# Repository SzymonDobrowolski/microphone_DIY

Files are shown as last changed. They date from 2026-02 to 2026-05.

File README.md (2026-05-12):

# High-Fidelity DIY USB Microphone 🎙️






<br>

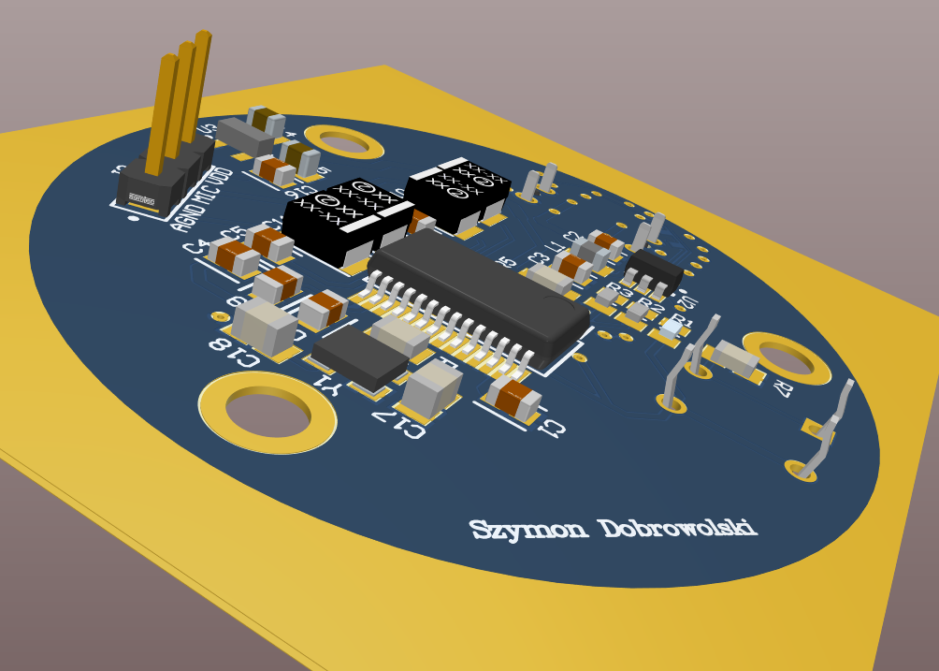
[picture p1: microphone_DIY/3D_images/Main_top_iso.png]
Main Board Isometric View


Welcome to the **High-Fidelity DIY USB Microphone** project repository! This project features a custom-designed, two-board USB audio interface and microphone preamplifier built from scratch. The primary goal of this project was to achieve a studio-grade vocal capture by combining a highly sensitive, interference-free custom PCB design with precise digital signal processing (DSP).

## 🌟 Key Features
* **Clean Signal Path:** Strict analog/digital isolation ensures the audio path is free from high-frequency digital bleed, coil whine, and USB packet noise.
* **Dual-Board Design:** Separates the noisy USB/Digital section (Main Board) from the highly sensitive analog preamplifier (Amp Board).
* **Advanced Power Filtering:** Features a $\pi$ (Pi) filter on the USB VBUS and a dedicated 3.3V LDO (MCP1700) with optimized decoupling.
* **Premium Analog Front-End:** Utilizes the ultra-low noise **OPA1688** operational amplifier to unleash the full dynamic range of high-end electret capsules like the **Primo AOM-5024L**.
* **Custom Acoustic Housing:** 3D-printed enclosure optimized for shock mounting and pop-filter integration to eliminate mechanical noise and plosives.
* **DSP Tuned:** Because the custom hardware captures the acoustic reality of the room with extreme sensitivity, precise real-time tuning (via SteelSeries Sonar) is applied to achieve a flawless broadcast character.

---

## ⚙️ Hardware Architecture

### 1. Main Board (USB Codec)
The main board handles USB communication, digital-to-analog/analog-to-digital conversion, and power regulation.

<p align="center">
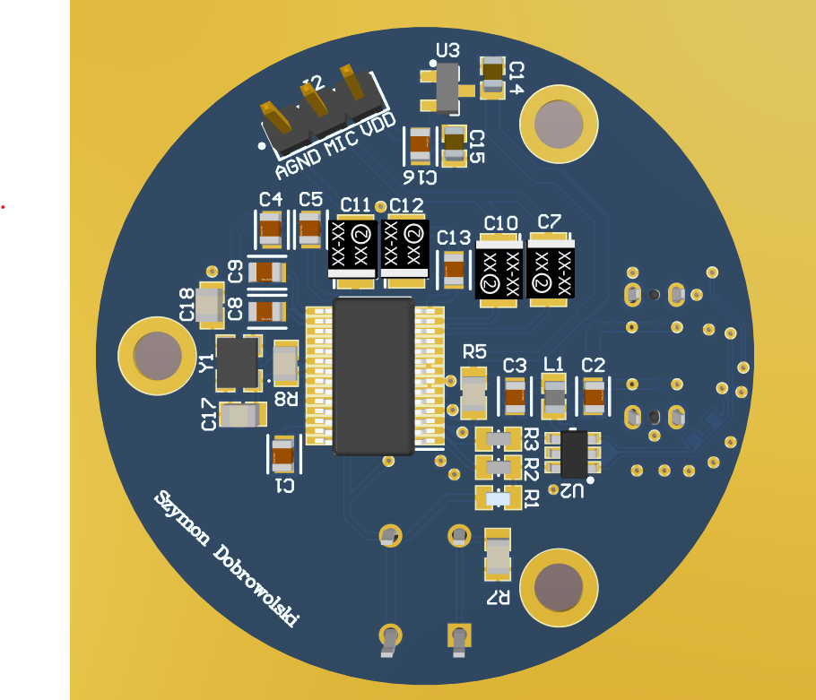
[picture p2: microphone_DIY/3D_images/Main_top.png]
Main Board Top
  
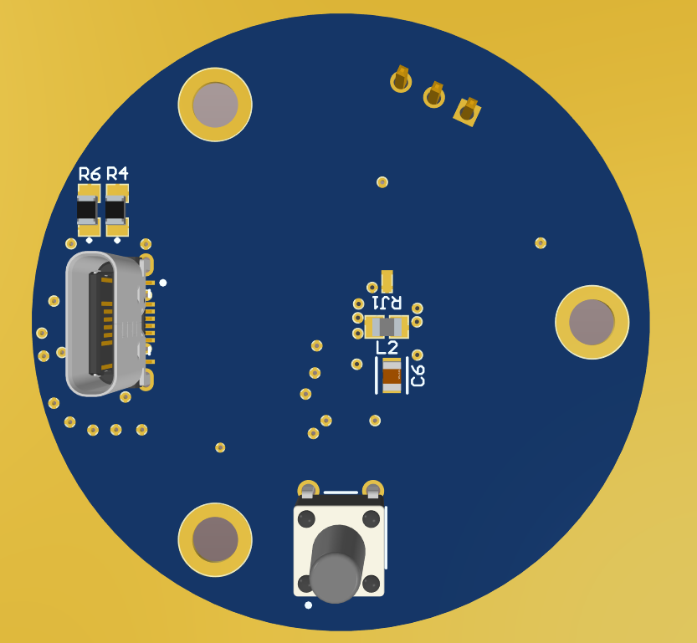
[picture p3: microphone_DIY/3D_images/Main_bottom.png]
Main Board Bottom
  
</p>

* **Audio Codec:** Texas Instruments **PCM2906C** (16-bit, 48kHz).
* **Connector:** USB Type-C.
* **Power Supply:** 5V to 3.3V conversion via **MCP1700** LDO.
* **Design Highlights:** Unused analog outputs are AC-coupled to ground to prevent oscillation. The highly sensitive `VCOM` pin is routed with priority and shielded with a solid analog ground plane.

### 2. Amp Board (Microphone Preamplifier)
The small, circular board is designed to be housed directly behind the microphone capsule.

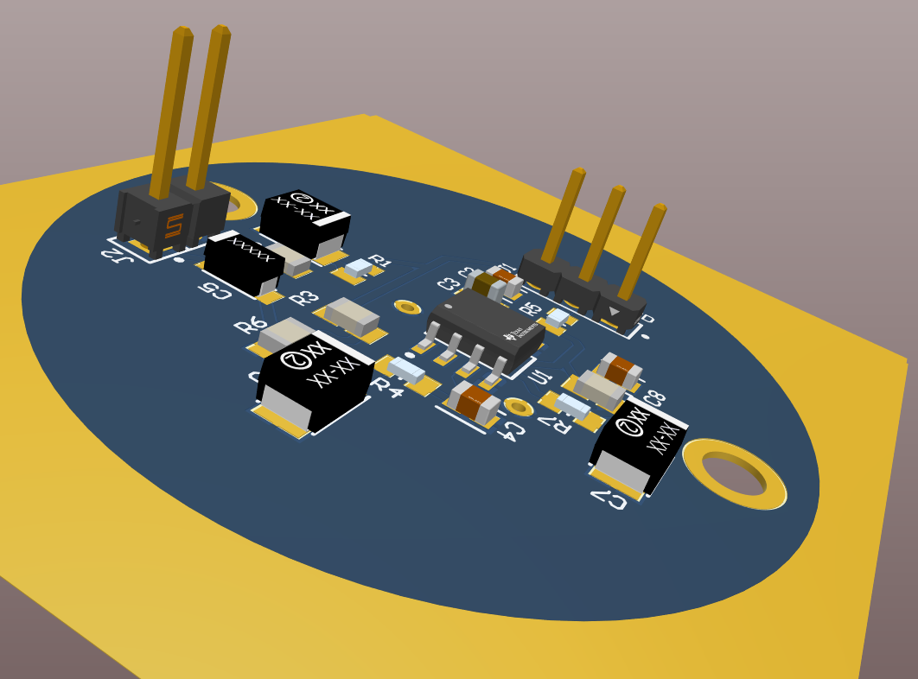
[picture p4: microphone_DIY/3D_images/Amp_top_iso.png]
Amp Board Isometric


* **Op-Amp:** Texas Instruments **OPA1688** configured with optimal gain (33 kΩ feedback resistor).
* **Input Filtering:** Features an RC filter on the microphone bias and an RF low-pass filter (100 Ω + 100 pF C0G capacitor) on the op-amp input to reject electromagnetic interference.
* **Coupling:** High-quality capacitors block DC offset while preserving low-frequency bass response.

### 3. Custom 3D-Printed Housing & Acoustics
To protect the sensitive electronics and ensure optimal acoustic performance, a dedicated housing was designed.
* **Acoustic Transparency:** The headbasket design allows sound waves to reach the capsule directly without causing unwanted internal reflections.
* **Vibration Isolation:** The enclosure is fully compatible with standard shock mounts to decouple the microphone from desk vibrations.
* **Plosive Control:** Designed to be used in tandem with an external pop filter, maintaining a minimum 5cm distance to effectively eliminate "P" and "B" wind blasts.

---

## 🎙️ Software Processing & DSP

While the custom hardware provides a high-gain, uncolored raw signal, the final "studio broadcast" character is achieved through digital processing.

**SteelSeries Sonar Configuration applied in this project:**
* **Base Preset:** "Deep Voice" for a warm, rich proximity effect.
* **ClearCast AI Noise Cancellation:** Set to ~65% to surgically remove any residual room noise without degrading vocal quality.
* **Smart Volume (Compressor):** Enabled to ensure a consistent, powerful, and professional output level regardless of speaking distance (optimal distance tested: ~20cm).

---

## 📊 Performance & Measurements

The circuit has been rigorously tested to ensure the absence of USB digital noise, high-frequency coil whine, and ground loops. 

### Spectrum Analysis (Vocal Performance & DSP)

The spectral analysis below demonstrates the frequency response of a recorded voice ("Harvard Sentences" test), showcasing the striking difference between the raw hardware output and the Sonar-processed signal. 

#### Raw vs. Processed Spectrum Comparison

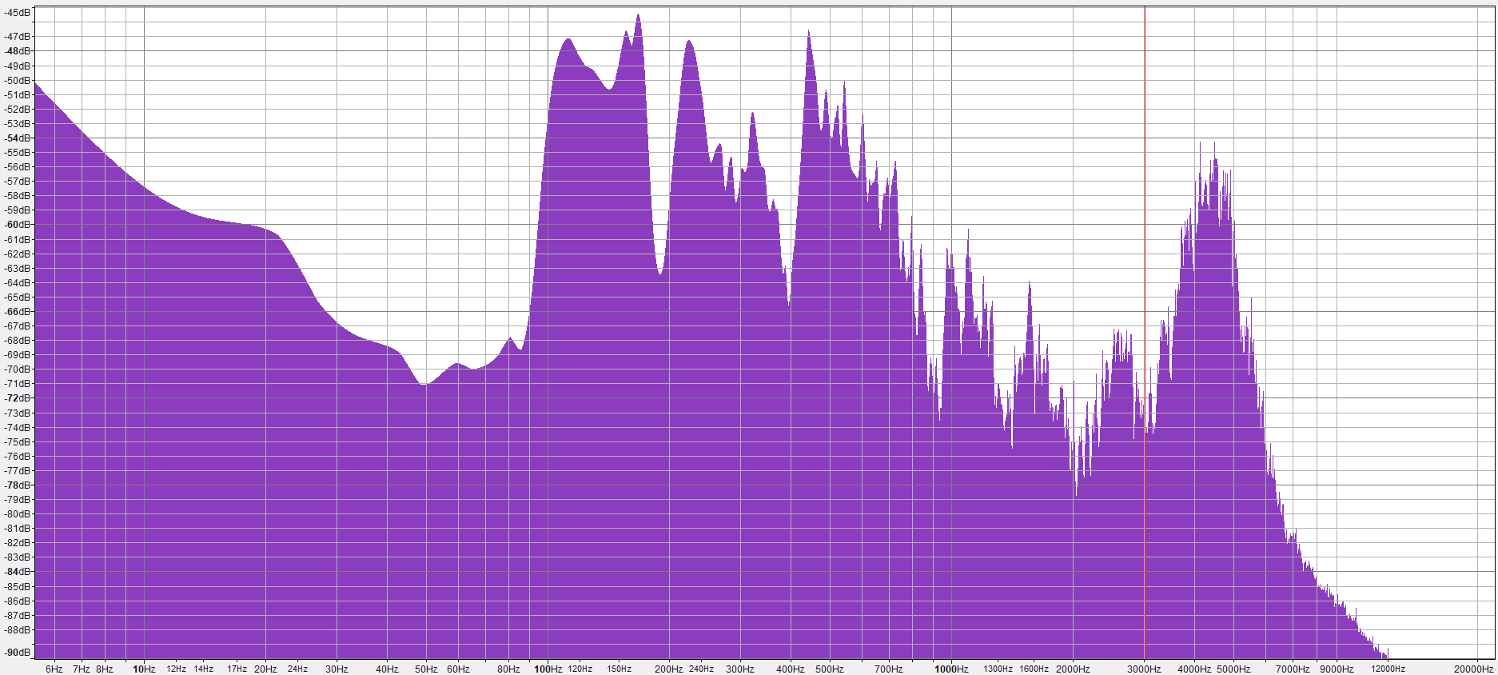
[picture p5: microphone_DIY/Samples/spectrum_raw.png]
Raw Signal Spectrum

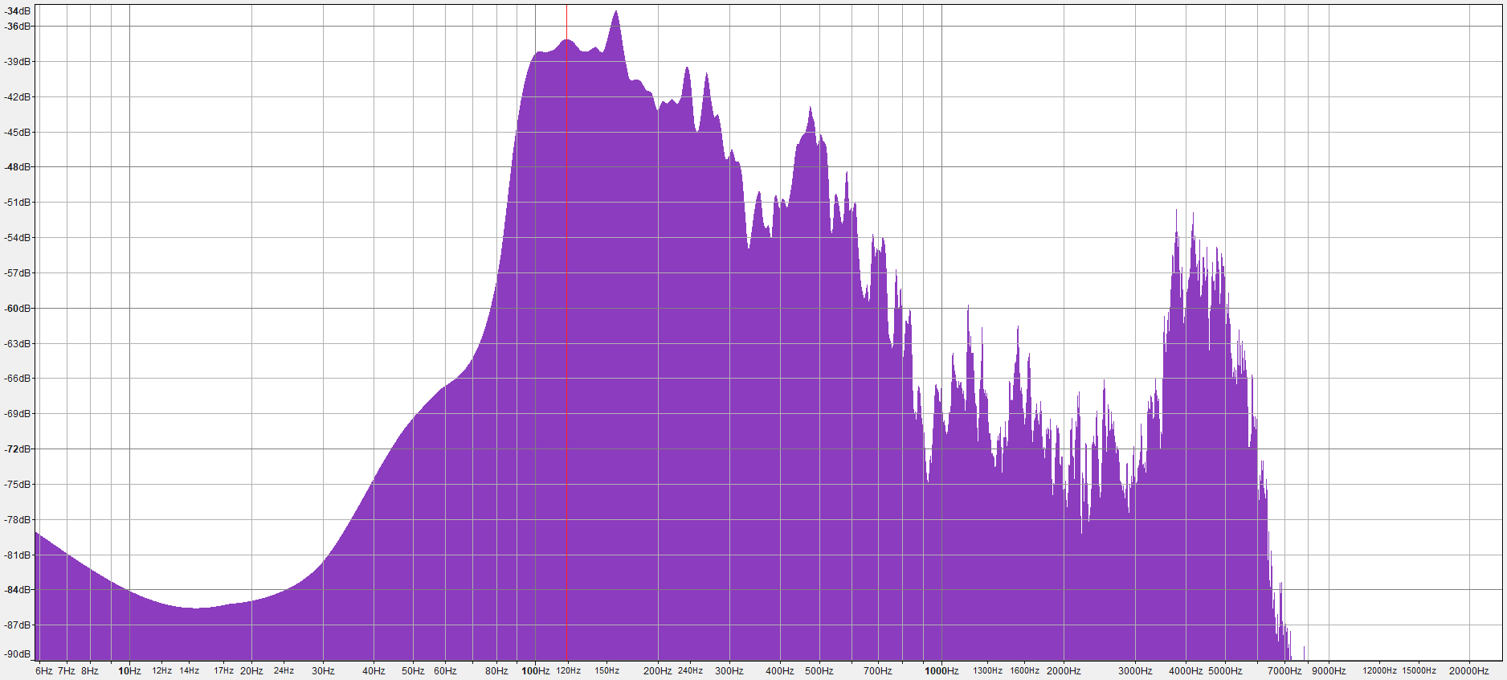
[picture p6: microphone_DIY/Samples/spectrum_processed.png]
Processed Signal Spectrum


* **Low-End (Below 90 Hz):** The highly sensitive capsule captures real room acoustics. The raw spectrum displays significant sub-bass rumble and room noise. In the processed spectrum, the 90Hz High-Pass Filter (HPF) successfully eliminates this useless acoustic noise, keeping the vocal fundamental incredibly clean.
* **Mid-Range (100 Hz - 500 Hz):** The raw signal features jagged, resonant peaks which typically cause a "boxy" or muddy sound in untreated rooms. The processed spectrum smooths this area out, maintaining a strong, warm fundamental vocal presence (peaking smoothly around 120-150Hz) while aggressively taming the muddy frequencies (280Hz cut).
* **High Frequencies & Sibilance (4 kHz - 8 kHz):** The raw spectrum has uncontrolled, harsh spikes in the sibilance range. The processed spectrum shows a much more controlled high-end, featuring a surgical roll-off and notch after 6-7 kHz to eliminate harsh "S" and "SH" sounds without losing vocal presence.

### Audio Samples (Raw vs. Processed)
Listen to the difference between the unprocessed signal and the final DSP-tuned output. The combination of the clean AOM-5024L hardware capture and DSP tuning produces a premium broadcast sound.

| Version | Description | Audio Player |
| :--- | :--- | :--- |
| **Raw Input** | Direct signal from the PCB | [sample_raw.mp3](https://github.com/user-attachments/files/27631429/sample_raw.mp3) |
| **Processed** | Final output with DSP | [sample_processed.mp3](https://github.com/user-attachments/files/27631450/sample_processed.mp3) |

---

## 📸 Final Project Showcase

Here is how the final, fully assembled DIY High-Fidelity Microphone looks in a real desktop environment:

<p align="center">
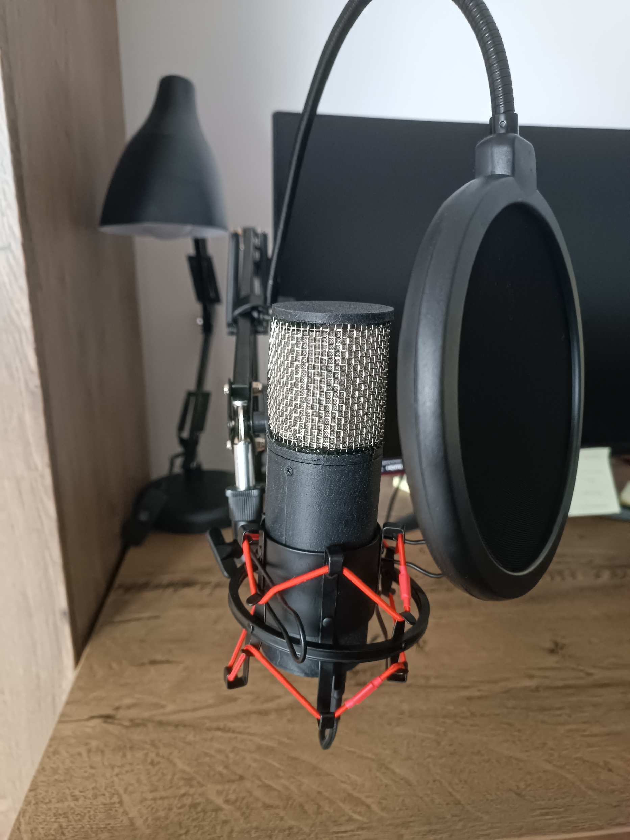
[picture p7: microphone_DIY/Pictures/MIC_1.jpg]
Microphone on arm
  
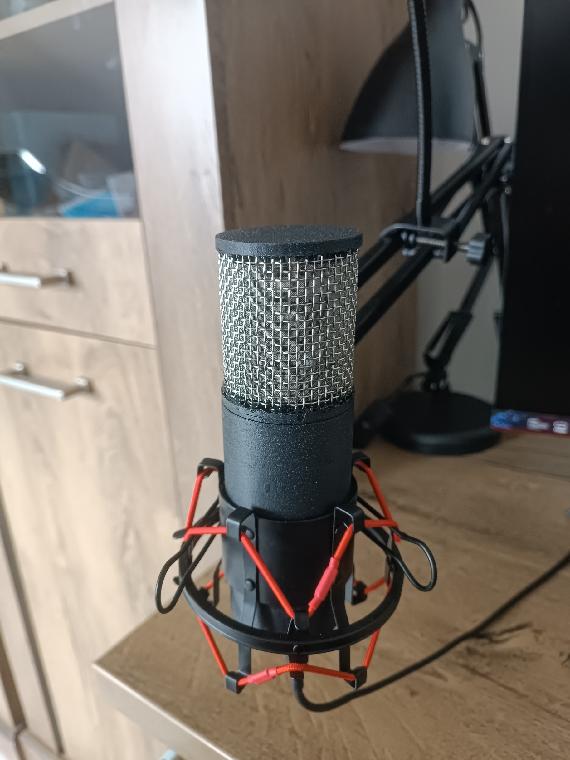
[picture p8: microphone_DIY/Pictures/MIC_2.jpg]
Microphone close-up
  
</p>

*(The setup includes the custom 3D-printed body, an external shock mount, and a pop-filter positioned for optimal off-axis rejection).*

---

## 📂 Repository Structure

* `3D_images/` - 3D renders of the PCBs and the microphone housing.
* `Pictures/` - Final build photos and spectrum analysis charts.
* `Samples/` - Audio test recordings (Raw and Processed).
* `_Previews/` - Image previews of the board layouts and schematics.
* `Project Logs...` & `Project Outputs...` - Altium Designer generation folders.
* `Main_board_schematic.pdf` & `Amp_board_schematic.pdf` - PDF schematics.
* `Main_gerber_files.zip` & `Amp_gerber_files.zip` - Production-ready Gerber and NC Drill files.
* `*.SchDoc`, `*.PcbDoc`, `*.PrjPcb` - Source design files (Altium Designer).

## 🛠️ Fabrication & Assembly
This project is fully ready for fabrication. You can directly upload the `.zip` Gerber files to your preferred PCB manufacturer. 
* **Component Footprints:** Mostly **0805** imperial code for easy hand-soldering.
* **Critical Components:** Ensure that C0G/NP0 dielectrics are used for pF-range capacitors in the audio path, and X7R/X5R for decoupling.

## 📝 License
Feel free to explore, clone, and modify this project for your own DIY audio interfaces!

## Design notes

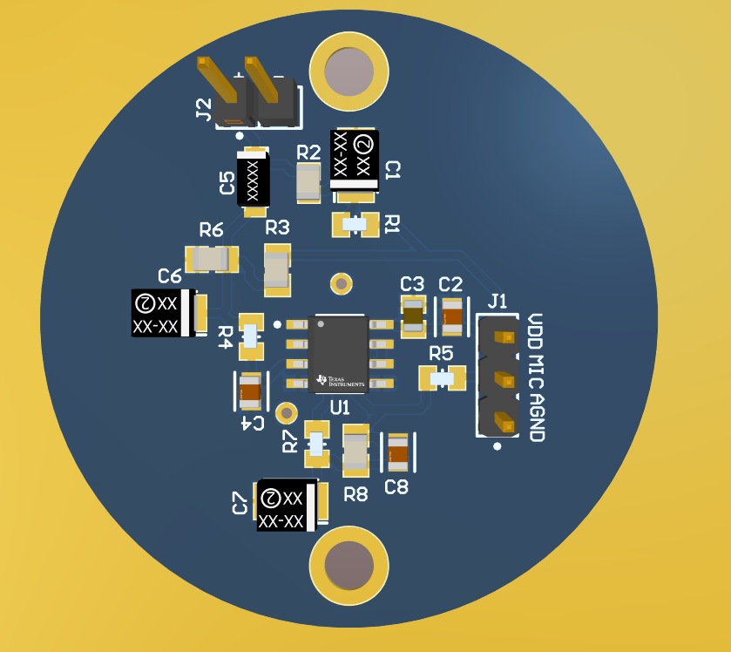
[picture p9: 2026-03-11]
microphone_DIY/3D_images/Amp_top.png

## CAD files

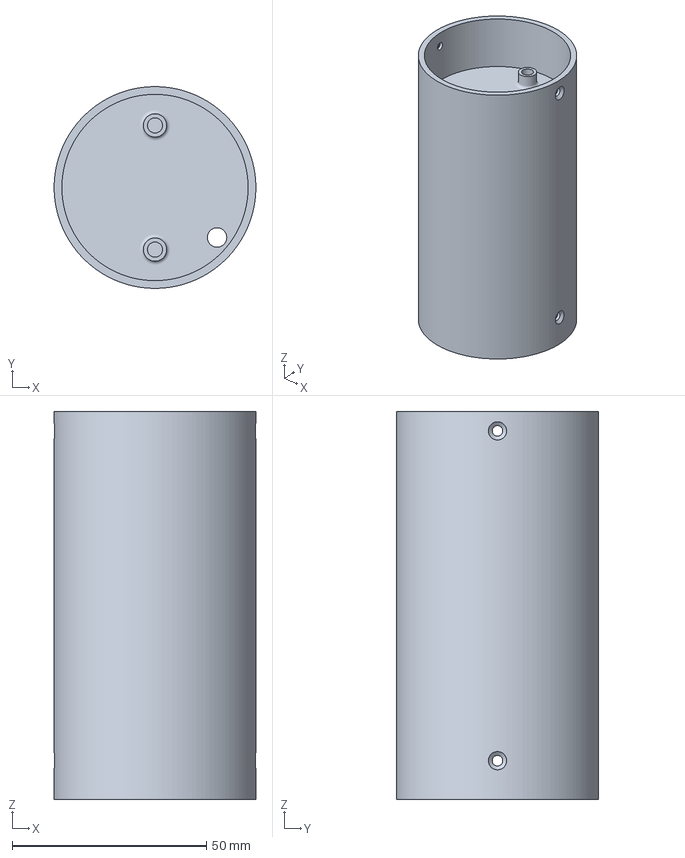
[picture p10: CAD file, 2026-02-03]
microphone_3D/Main_files/Mic_main_3mf.3mf
52.0 x 52.0 x 100.0 mm

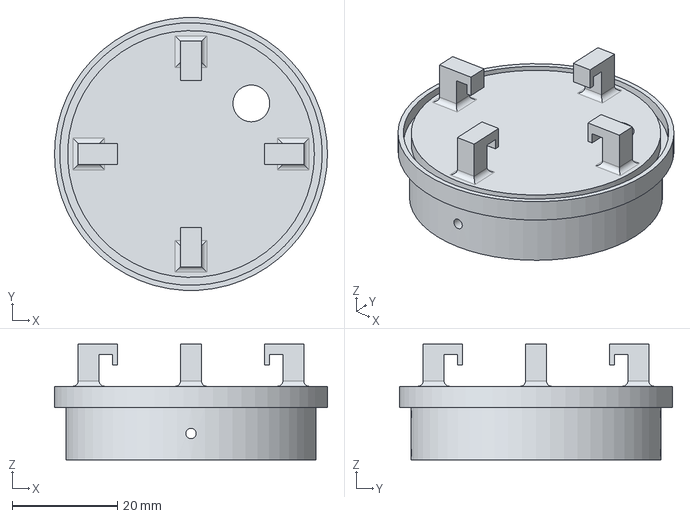
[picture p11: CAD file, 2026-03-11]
microphone_3D/Main_files/Mic_top.step
52.0 x 51.9 x 22.0 mm

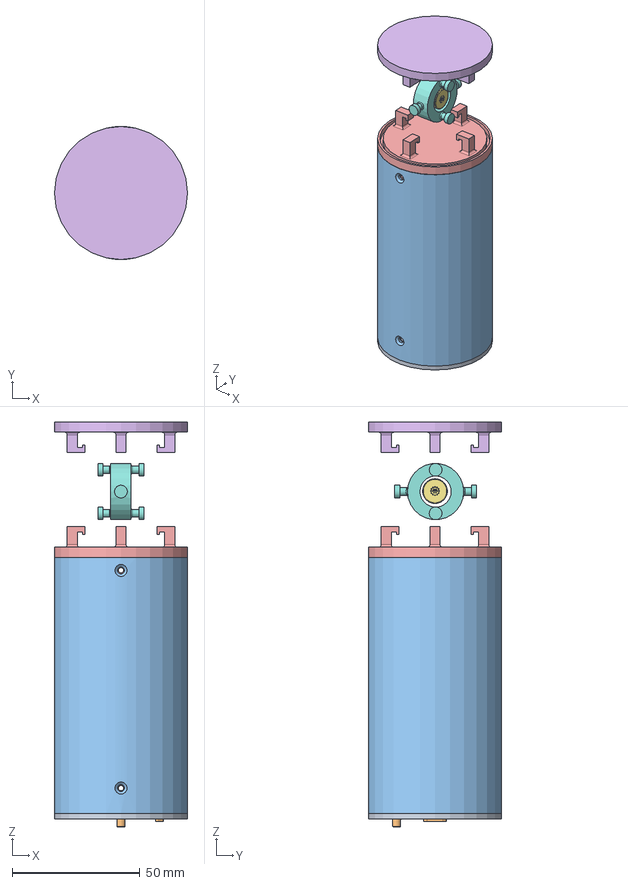
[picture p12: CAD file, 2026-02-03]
microphone_3D/Presentation/Mic_all.FCStd
52.0 x 52.0 x 158.2 mm
Mic_bottom1_001
microphone_DIY1_001
Mic_main1_001
microphone_DIY_top1_001
Mic_top1_001
Mic_top_top1_001
AOM-5024L-HD-R1_001
Mic_housing1_001

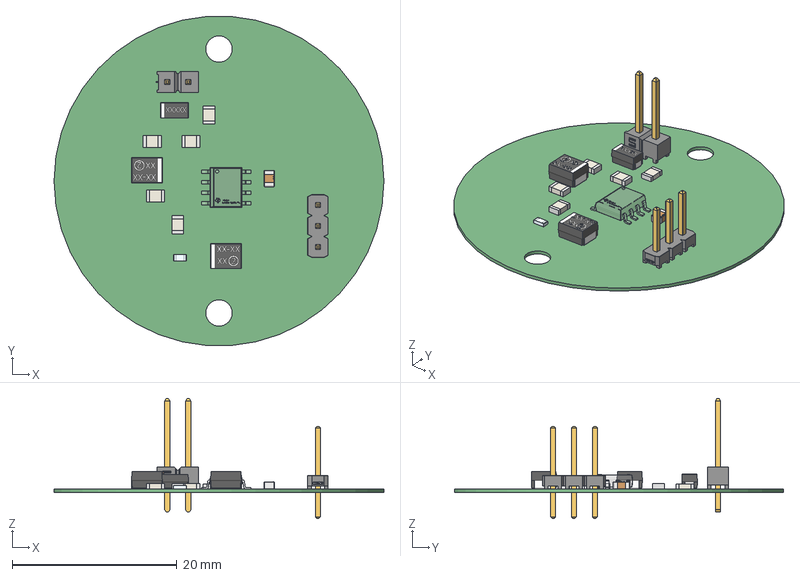
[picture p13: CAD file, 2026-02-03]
microphone_3D/Presentation/microphone_DIY_top.step
40.0 x 39.9 x 14.6 mm
IC_BODY
circle
IC_LEG x 4
Texas Instruments
IC_LEG_MIR8 x 4
Extruded x 15
CPF0805B22RE1
T-1S6-08-TSW-1-14-2-S
TSW-102-14-G-S_body
Samtec Logo
MTLW-103-07-G-S-230_body
MTLW-03-07-S-230
Pin1_Triangle
Samtec
593D106X9016B2TE3 x 2
293D105X9016A2TE3
terminals
logo

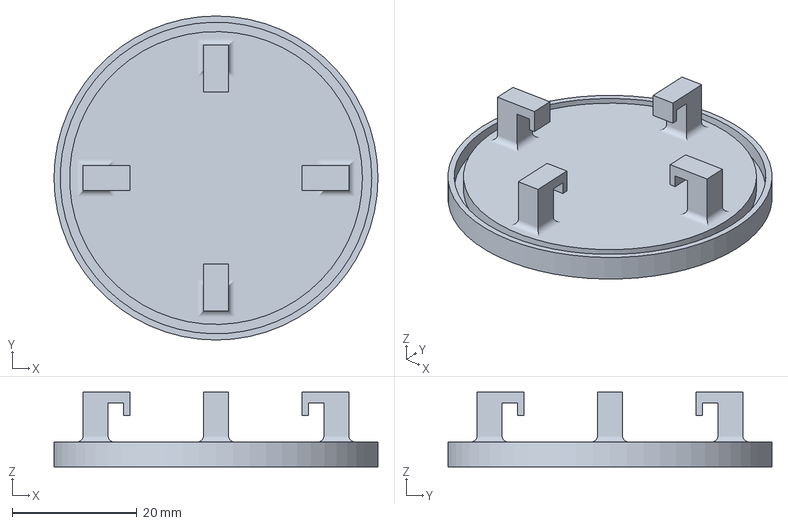
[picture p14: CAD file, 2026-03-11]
microphone_3D/Main_files/Mic_top_top_3mf.3mf
52.0 x 52.0 x 12.0 mm

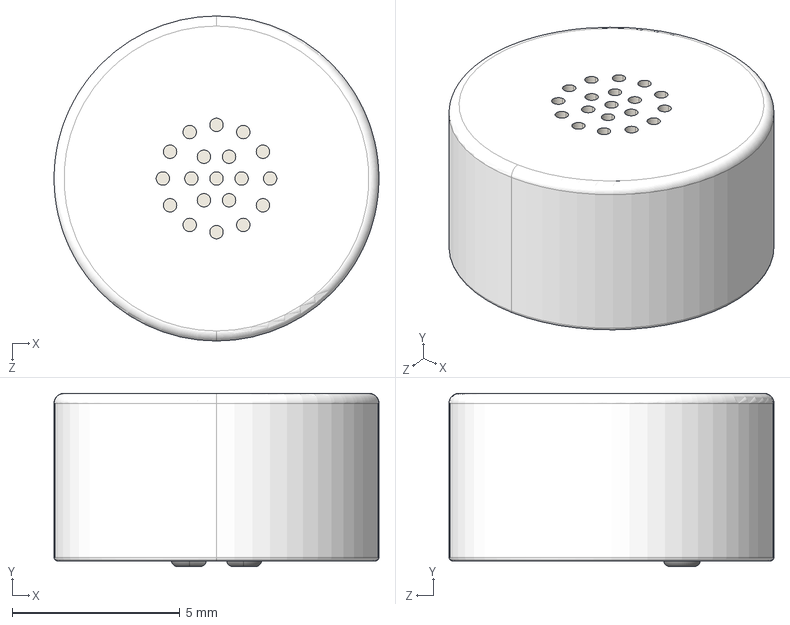
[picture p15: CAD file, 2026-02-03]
microphone_3D/Presentation/AOM-5024L-HD-R.stp
9.70 x 5.17 x 9.70 mm

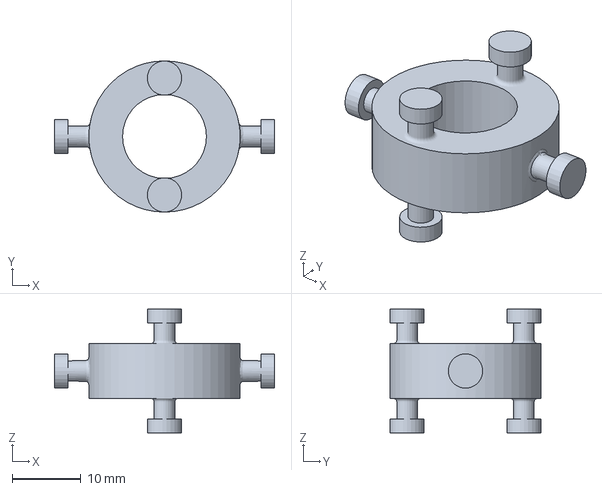
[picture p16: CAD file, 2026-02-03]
microphone_3D/Main_files/Mic_housing_3mf.3mf
32.0 x 22.0 x 18.0 mm

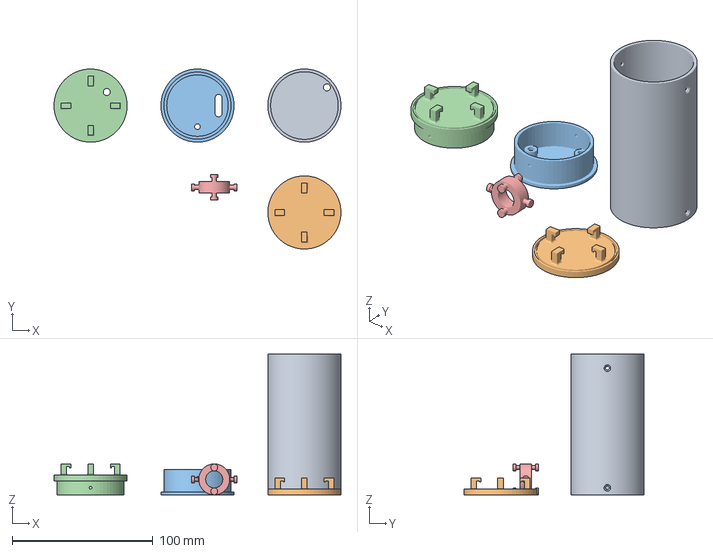
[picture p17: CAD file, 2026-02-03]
microphone_3D/Main_files/Mic_bottom_3mf.3mf
204.0 x 127.9 x 100.0 mm

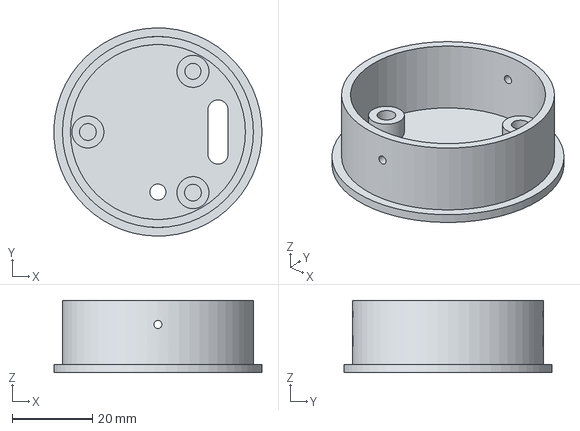
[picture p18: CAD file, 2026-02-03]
microphone_3D/Main_files/Mic_bottom.step
52.0 x 52.0 x 18.0 mm

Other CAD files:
microphone_3D/Main_files/Mic_main.step
microphone_3D/Main_files/Mic_top_3mf.3mf
microphone_3D/Main_files/Mic_top_top.step
microphone_3D/Main_files/Mic_housing.step
microphone_3D/Main_files/Mic_bottom.FCStd
microphone_3D/Main_files/Mic_housing.FCStd
microphone_3D/Main_files/Mic_main.FCStd
microphone_3D/Main_files/Mic_top.FCStd
microphone_3D/Main_files/Mic_top_top.FCStd

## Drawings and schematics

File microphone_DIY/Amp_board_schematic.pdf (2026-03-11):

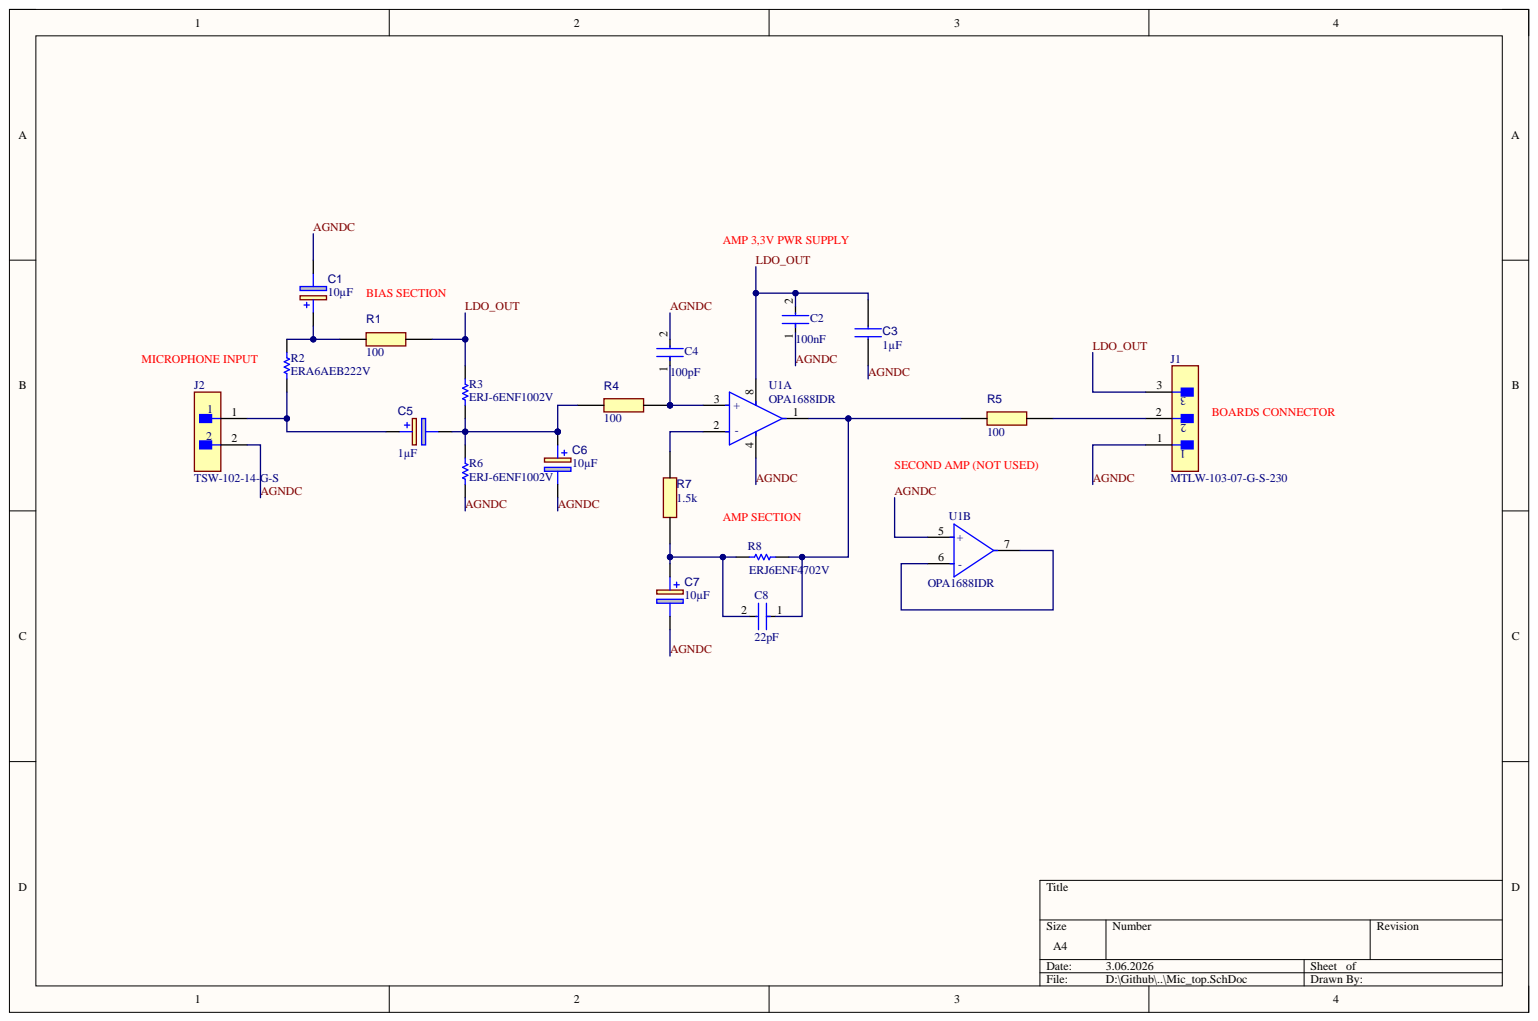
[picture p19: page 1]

SECOND AMP (NOT USED)

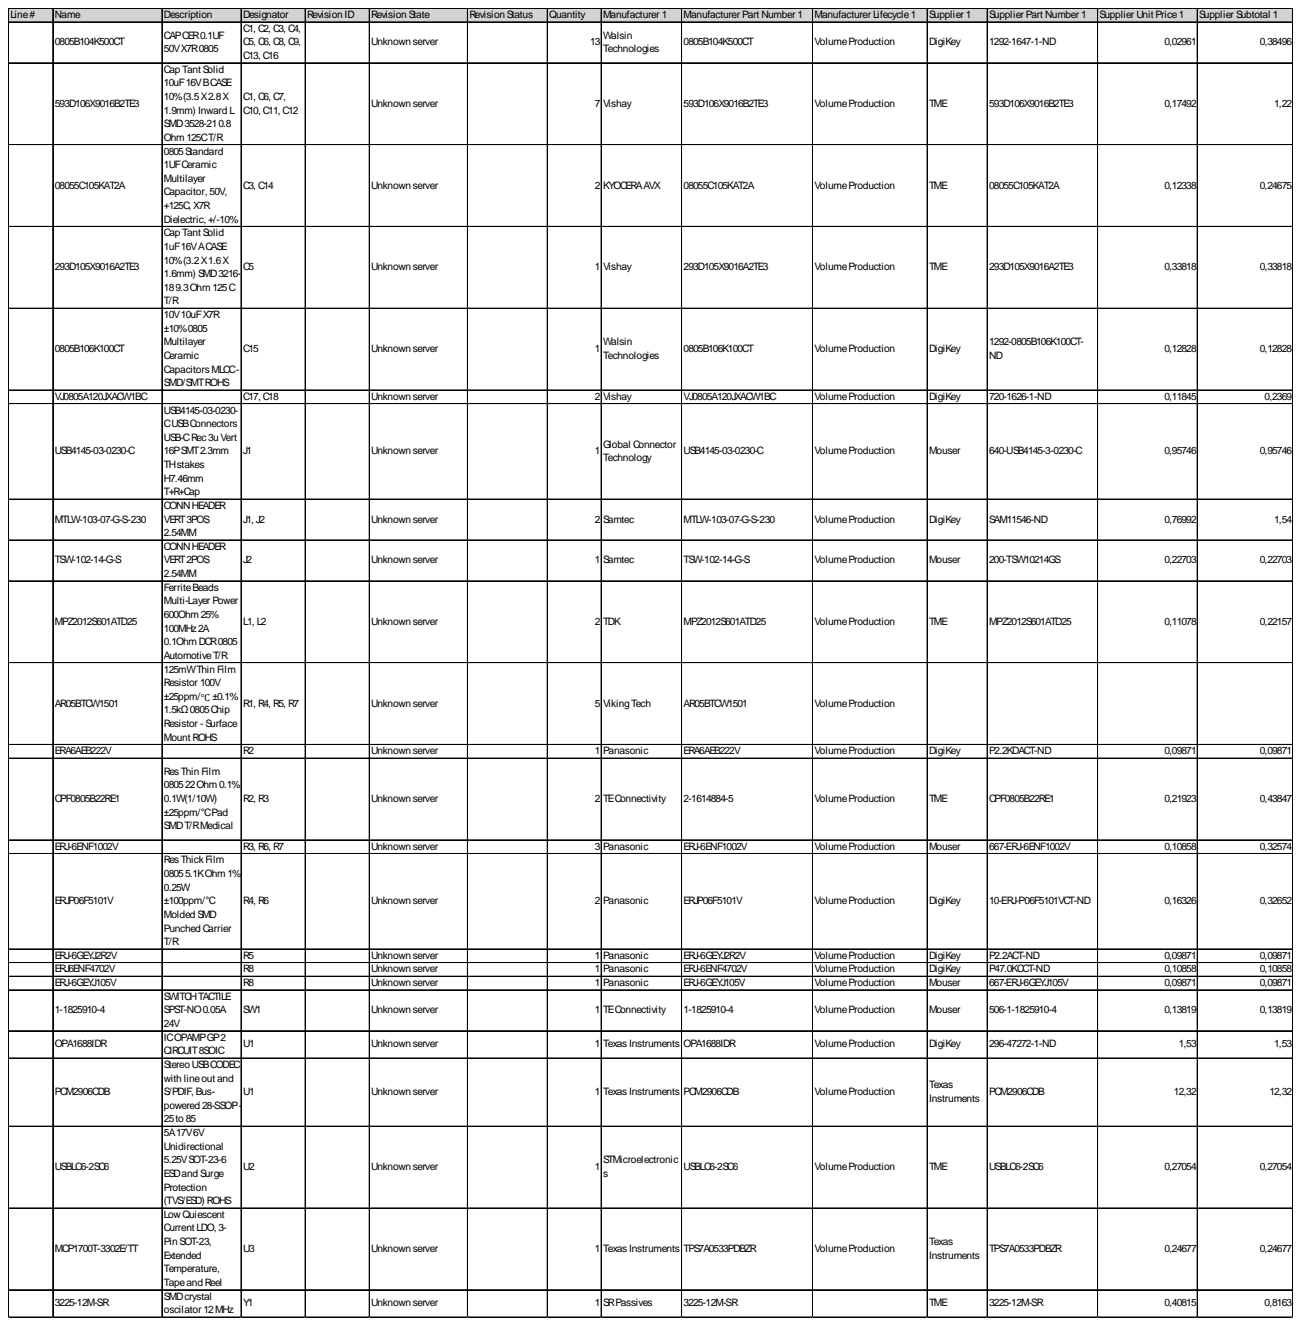
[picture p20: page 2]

Line# | Name | Description | Designator | Revision ID | Revision State | Revision Status | Quantity | Manufacturer 1 | Manufacturer Part Number 1 | Manufacturer Lifecycle1 | Supplier 1 | Supplier Part Number 1 | Supplier Unit Price1 | Supplier Subtotal 1

0805B104K500CT | CAPCER0.1UF 50VX7R0805 | C1, C2, C3, C4, C5, C6, C8, C9, C13, C16 | | Unknown server | | 13 Walsin | Technologies | 0805B104K500CT | VolumeProduction | DigiKey | 1292-1647-1-ND | 0,02961 | 0,38496

593D106X9016B2TE3 | Cap Tant Solid 10uF16VBCASE 10%(3.5X2.8X 1.9mm) Inward L SMD3528-210.8 Ohm 125CT/R | C1, C6, C7, C10, C11, C12 | | Unknown server | | 7 Vishay | | 593D106X9016B2TE3 | VolumeProduction | TME | 593D106X9016B2TE3 | 0,17492 | 1,22

08055C105KAT2A | 0805Standard 1UFCeramic Multilayer Capacitor, 50V, +125C, X7R Dielectric, +/-10% | C3, C14 | | Unknown server | | 2 KYOCERAAVX | | 08055C105KAT2A | VolumeProduction | TME | 08055C105KAT2A | 0,12338 | 0,24675

293D105X9016A2TE3 | Cap Tant Solid 1uF16VACASE 10%(3.2X1.6X 1.6mm) SMD3216-189.3Ohm 125C T/R | C5 | | Unknown server | | 1 Vishay | | 293D105X9016A2TE3 | VolumeProduction | TME | 293D105X9016A2TE3 | 0,33818 | 0,33818

0805B106K100CT | 10V10uFX7R ±10%0805 Multilayer Ceramic Capacitors MLCC-SMD/SMTROHS | C15 | | Unknown server | | 1 Walsin | Technologies | 0805B106K100CT | VolumeProduction | DigiKey | 1292-0805B106K100CT-ND | 0,12828 | 0,12828

VJ0805A120JXACW1BC | | C17, C18 | | Unknown server | | 2 Vishay | | VJ0805A120JXACW1BC | VolumeProduction | DigiKey | 720-1626-1-ND | 0,11845 | 0,2369
USB4145-03-0230-C | USB4145-03-0230-CUSBConnectors USB-CRec 3u Vert 16PSMT2.3mm THstakes H7.46mm T+R+Cap | J1 | | Unknown server | | 1 Global Connector | Technology | USB4145-03-0230-C | VolumeProduction | Mouser | 640-USB4145-3-0230-C | 0,95746 | 0,95746

MTLW-103-07-G-S-230 | CONN HEADER VERT3POS 2.54MM | J1, J2 | | Unknown server | | 2 Samtec | | MTLW-103-07-G-S-230 | VolumeProduction | DigiKey | SAM11546-ND | 0,76992 | 1,54

TSW-102-14-G-S | CONN HEADER VERT2POS 2.54MM | J2 | | Unknown server | | 1 Samtec | | TSW-102-14-G-S | VolumeProduction | Mouser | 200-TSW10214GS | 0,22703 | 0,22703

MPZ2012S601ATD25 | FerriteBeads Multi-Layer Power 600Ohm 25% 100MHz2A 0.1Ohm DCR0805 AutomotiveT/R | L1, L2 | | Unknown server | | 2 TDK | | MPZ2012S601ATD25 | VolumeProduction | TME | MPZ2012S601ATD25 | 0,11078 | 0,22157

AR05BTCW1501 | 125mWThin Film Resistor 100V ±25ppm/℃ ±0.1% 1.5kΩ0805Chip Resistor - Surface Mount ROHS | R1, R4, R5, R7 | | Unknown server | | 5 VikingTech | | AR05BTCW1501 | VolumeProduction

ERA6AEB222V | | R2 | | Unknown server | | 1 Panasonic | | ERA6AEB222V | VolumeProduction | DigiKey | P2.2KDACT-ND | 0,09871 | 0,09871

CPF0805B22RE1 | Res Thin Film 080522Ohm 0.1% 0.1W(1/10W) ±25ppm/°CPad SMDT/RMedical | R2, R3 | | Unknown server | | 2 TEConnectivity | | 2-1614884-5 | VolumeProduction | TME | CPF0805B22RE1 | 0,21923 | 0,43847

ERJ-6ENF1002V | | R3, R6, R7 | | Unknown server | | 3 Panasonic | | ERJ-6ENF1002V | VolumeProduction | Mouser | 667-ERJ-6ENF1002V | 0,10858 | 0,32574
ERJP06F5101V | Res Thick Film 08055.1KOhm 1% 0.25W ±100ppm/°C Molded SMD Punched Carrier T/R | R4, R6 | | Unknown server | | 2 Panasonic | | ERJP06F5101V | VolumeProduction | DigiKey | 10-ERJ-P06F5101VCT-ND | 0,16326 | 0,32652

ERJ-6GEYJ2R2V | | R5 | | Unknown server | | 1 Panasonic | | ERJ-6GEYJ2R2V | VolumeProduction | DigiKey | P2.2ACT-ND | 0,09871 | 0,09871
ERJ6ENF4702V | | R8 | | Unknown server | | 1 Panasonic | | ERJ-6ENF4702V | VolumeProduction | DigiKey | P47.0KCCT-ND | 0,10858 | 0,10858
ERJ-6GEYJ105V | | R8 | | Unknown server | | 1 Panasonic | | ERJ-6GEYJ105V | VolumeProduction | Mouser | 667-ERJ-6GEYJ105V | 0,09871 | 0,09871
1-1825910-4 | SWITCHTACTILE SPST-NO0.05A 24V | SW1 | | Unknown server | | 1 TEConnectivity | | 1-1825910-4 | VolumeProduction | Mouser | 506-1-1825910-4 | 0,13819 | 0,13819

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

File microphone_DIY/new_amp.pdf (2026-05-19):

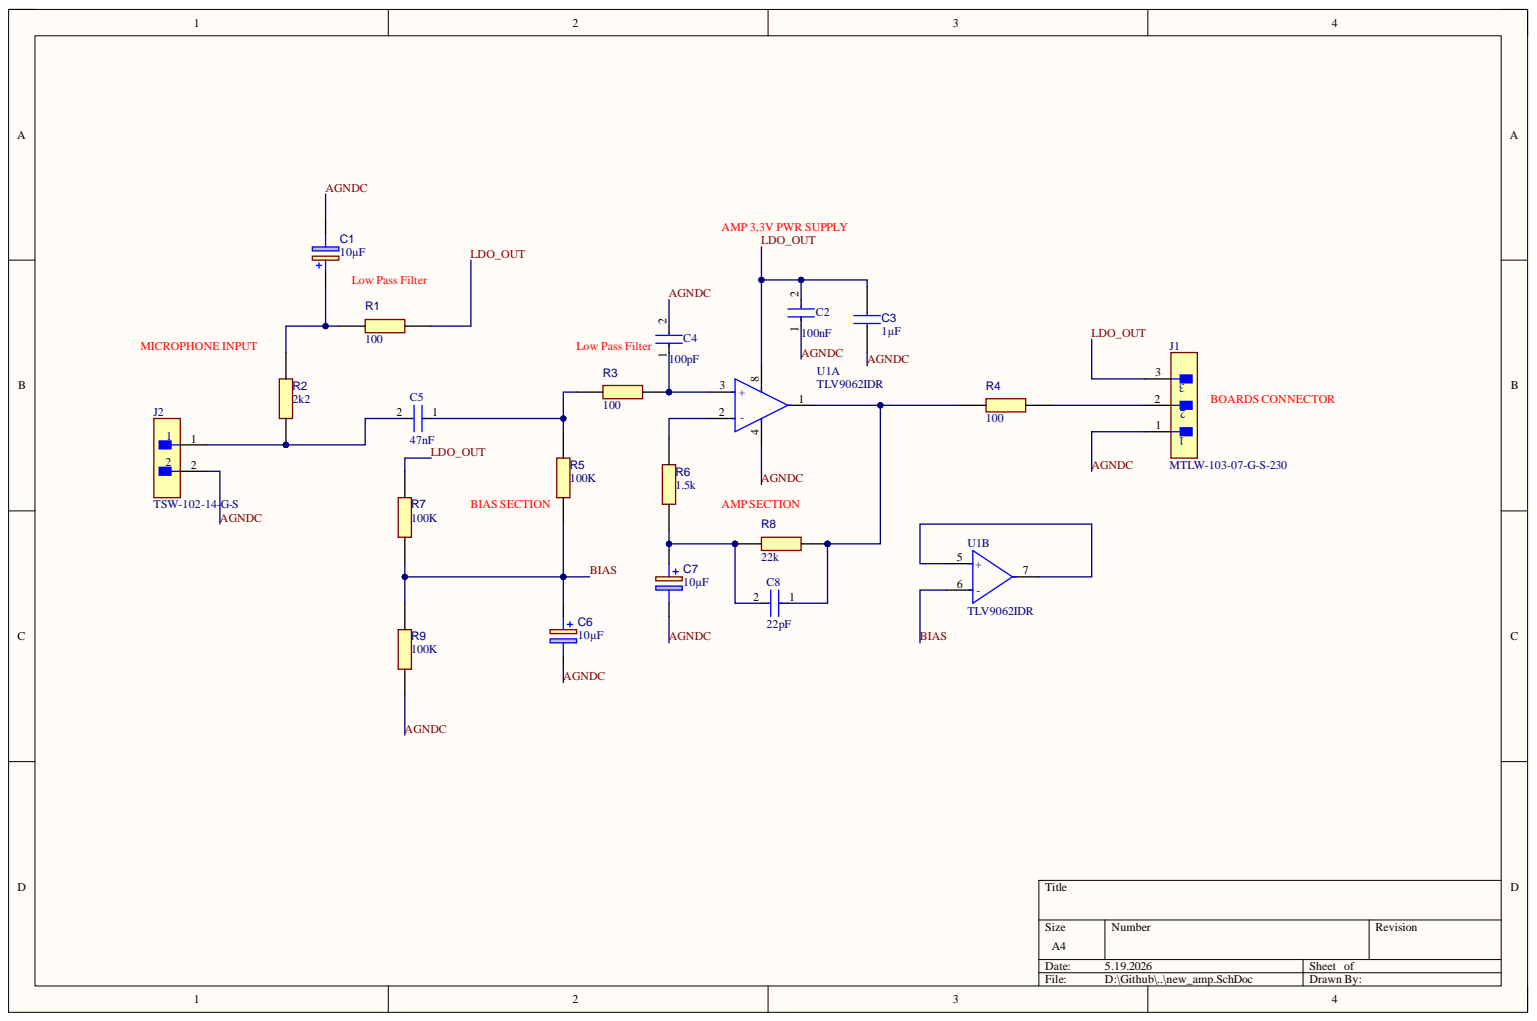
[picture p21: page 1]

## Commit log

2026-01-27 BOM and schematic
    [microphone_DIY.PrjPcb, microphone_DIY.SchDoc]
2026-02-03 PCB added and 3D case
    [AOM-5024L-HD-R.stp, Mic_all.FCStd, Mic_bottom.FCStd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]
2026-02-06 pcb done
    [Mic_top.SchDoc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]
2026-03-11 new pcb design, after amp board fix
    [Mic_top.FCStd, Mic_top.SchDoc, Mic_top.step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]
2026-03-11 Update README with images and text improvements
    Added images for main board and amp board, and improved performance section wording.
2026-05-12 samples, frequency analysis, photos of microphone
2026-05-12 Revise README for clarity on features and processing
    Updated project description and key features to emphasize vocal capture and DSP tuning. Removed performance measurements section and added details about the custom 3D-printed housing and software pro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
2026-05-12 Fix links for audio samples in README
2026-05-12 Change audio file links to audio players in README
    Updated audio sample section to use audio players instead of links.
2026-05-12 Update audio sample links in README
2026-05-12 Enhance README with audio sample links and controls
    Added audio controls and links for raw and processed audio samples.
2026-05-12 Change audio sample links from MP3 to MP4
    Updated audio sample links in README to use MP4 format.
2026-05-12 Update audio samples in README to MP3 links
2026-05-19 new amp pcb design
    [Mic_top.SchDoc, microphone_DIY.PrjPcb, microphone_DIY.SchDoc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]
